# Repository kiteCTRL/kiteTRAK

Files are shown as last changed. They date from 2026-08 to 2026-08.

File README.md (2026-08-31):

# kiteTRAK for PhobGCC

  

## How it Works
A QtPy RP2040 microcontroller is added to the controller to read the PhobGCC state and drive the 128x64 OLED display. The PhobGCC and QtPy RP2040 utilize DMA-based SPI communication for extremely fast comm speeds without interrupting the PhobGCC and maintaining reliable controller functionality. The QtPy RP2040 and OLED display are powered via the 5V line, replacing the rumble motor. The current draw is measured to be 30-40mA, which is about the same current draw as the rumble motor during steady-state use.

Hardware, firmware, and rumble motor bracket 3D model designed by me and top-shell, screen cover, and tall start button 3D models designed by Olympia https://github.com/sean44104 (thank you!).

## Features and Use

### Menu Navigation
PXL_20260826_155146718 (1)  

* Press Z + D-pad Left/Right to navigate the multiple modes with visuals showing which mode you are about to select
* Releasing Z (or while holding, pressing D-pad Up/Down) will exit the menu navigation into the mode you are seeing
* Pressing Z + D-pad Up/Down will navigate the various views within the mode you are in
* Holding Z + Start for 3 seconds on any of the below views will set that to be the default screen after booting
    * There is also a lock icon displayed in the top-right to let you know if your Phob has safe mode enabled (locked icon) or disabled (unlocked icon)

### Button Mode
PXL_20260826_154814305 (1)  

* View main stick and C stick values with visual display
* View analog trigger values and digital button inputs with visual display
* View dashboard of all analog and digital inputs in one simple look  

### IPM Mode
rn_image_picker_lib_temp_c69bd927-668b-4897-ad5c-2858ec075ff4 (1)  

* View your Inputs per Minute (IPM) with a large number in the center of the screen
* View your IPM with a plot showing its change over time
    * If you reach a high-enough IPM, a Balatro-inspired fire animation will be displayed in either view

### Timer Mode
PXL_20260826_160518765 (1)  

* Display the total time since your controller has been plugged in

### Animation Mode
PXL_20260826_160734884 (1)  

* Display a fire animation
* Display a rain animation
* Display a water puddle reactive animation based on digital controller inputs

### Calibration Mode
PXL_20260826_161128514 (1)  

* Display a QR code to access the PhobGCC Calibration guide
* Stick Calibration: A guided process to calibrate either stick, while showing you their exact values with a visual aid
    * If you press D-pad down, this will toggle a help menu for what you are doing at each segment of the calibration process
* A/C-Stick Settings: View your settings for X/Y snapback filtering, waveshaping, smoothing, scaling, and cardinal snapping
    * Holding C stick down during this and all following views will show you help and the button inputs needed to adjust all settings shown
* Trigger Settings: View your settings for L/R trigger modes and L/R offset values
* Button Remaps: View your current button remap settings for A, B, D-pad Up, L, R, X, Y, and Z buttons

---

## Equipment Needed
* Soldering equipment
* Wire strippers
* Flush cutters
* Y1 Tri-Wing screwdriver
* P1 Philips screwdriver
* T6 Torx screwdriver

## Parts Needed

### Controller
* PhobGCC 2.x controller
    * If you are making a new PhobGCC controller for this project, refer to the PhobGCC build guide for details: https://phobgcc.com/For_Makers/Build_Guide_2.0.html
* Custom 3D printed components:
    * Top-shell
    * Screen cover
    * Rumble motor bracket
    * Tall start button
    * Olympia removable gateplate: https://github.com/sean44104/Removable-Gate-GCC

If 3D printing parts with JLCPCB, I recommend the following materials and surface finish:
* Top-shell: JLC Black Resin (more durable) or Imagine Black Resin (better surface finish) with General Sanding
* Screen cover: Imagine Black Resin with General Sanding
* Rumble motor bracket: JLC Black Resin with General Sanding
* Tall start button: Grey Resin (replicates look of OEM start button)
* Olympia removable gateplate: 8001 Resin Transparent with Oil Spraying or 9600R White Resin with General Sanding
    * Note: You will receive a warning for a print thickness <0.8mm with JLC, you can accept this warning

### Electronics
* 1x Adafruit QtPy RP2040 microcontroller
* 1x Adafruit Monochrome 0.96" 128x64 OLED Display
* 1x Adafruit 50mm STEMMA QT cable
* 1x 4pin XA JST header (male and female)
* 1x 2pin XA JST header (male and female)
* 3x 6" XA JST jumper cables
    - All parts above can be found in this DigiKey list: https://www.digikey.com/en/mylists/list/08I1ISAMJL

### Hardware
* 7x M2x0.4mm screw-to-expand press-in inserts (90363A110)
* 3x 6mm M2x0.4mm flat-head Torx screws (90236A104)
* 4x 8mm M2x0.4mm pan-head Torx screws (90304A325)
* Recommended: Multipurpose mineral oil lubricant (1244K14)
    - Part numbers added to find on McMaster-Carr

---

## Installation

### Preparing the Top-shell
  

1. Press in the 7x screw-to-expand threaded inserts in the following positions with the caps facing up:  
    * Note: If threaded inserts do not press fit with just a little force, use the P1 Philips screwdriver to slowly carve away some of the inner plastic materials in the insert posts. Make sure to only remove a small amount of material at a time to avoide loose inserts.

<br>

PXL_20260826_005752434 (1)  

2. After all inserts are installed, use the pan-head Torx screws to expand and tighten down the inserts until flush:  

<br>
  
PXL_20260826_010112606 (1)  

3. Attach the STEMMA QT cable to the right side header of the OLED display and feed it through the gap on the top-shell:  

<br>

PXL_20260826_010610511 (1)  

4. Press the OLED display into place, add screen cover on-top of display, and use the 4x 8mm pan-head Torx screws to mount the screen to the top-shell:  
    * Note: If OLED display does not want to fit into the top-shell, you may need to carve some of the top-shell side material where the headers fit into the gaps. Do NOT force the OLED display as it may break.

<br>

PXL_20260826_010826354 (1)  

5. Press your Olympia removable gateplate into the top-shell and use the 3x flat-head Torx screws to mount the gateplate to the top-shell. Once completed, the top-shell assembly should look like this when complete:
    * Note: Due to print variations, the stick's rubber may contact the gateplate causing a poor feel to stick travel along the notches. To fix, add some filler material inside the stick's post to raise the stick slightly.

<br>

### Installing the QtPy RP2040
  

  

1. Insert and solder the female XA JST headers to the QtPy RP2040 as shown above. Also, trim the soldered pins so they are nearly flush with the PCB.  
    * Note: The headers will be facing opposite directions due to space constraints. Also, the 4-pin XA JST header will sit on the ridge of the reset button, make sure it is not being pressed down when installing.

<br>
  
PXL_20260826_015955598 (1)  

2. Cut the 3x 6" XA JST jumper cables in half to make 6x 3" cables, each with one pin. Strip 4x of the cables to expose the wires on the non-pin ends. Insert and solder the wires into the back-side of the Phob board's GPIO breakout pins labeled GP12-GP15 as shown above:  

<br>
  
rn_image_picker_lib_temp_c13a6599-646f-4fae-9a03-d20db38ac024 (1)  

3. Insert the pins into the XA JST male header with the following wires mounting to the following header holes:  

<br>
  
PXL_20260826_021211120 (1)  

4. With the 2x remaining wires, cut their length down to ~1.5" and strip the non-pin end to expose the wires. Solder one wire to the '+' side of the rumble pin and the other to the square ground pin of the PhobVision pins, located above the rumble pins. Insert the pins into the XA JST male header, routing the ground connection to the left side and the positive connection to the right side of the header in the above orientation:  

<br>

PXL_20260826_022255254 (1)  

5. Fit the 4-pin XA JST header through the opening of the rumble motor bracket and move the 2-pin XA JST header out of the way. Insert the trigger boards into place, and press the rumble motor bracket down as above:  

<br>

PXL_20260826_022522808 (1)  

6. Mount the cable headers into the QtPy RP2040 and move it into the space in the center of the bracket. The installed QtPy RP2040 will sit as shown above:
    * Note: Make sure to route the 4x GPIO wires so they are in front of the 'T' post to avoid interfering with the back-shell when closing. Also, the headers should fit into a small recess that dips down towards the board. 

Now would be a good time to flash the firmware for the Phob board and the QtPy RP2040. Press and hold the reset button on the boards during USB mount to allow flashing the .uf2 files found in [Releases](https://github.com/kiteCTRL/kiteTRAK/releases/latest). Make sure to only have one USB plugged in at a time when flashing. THIS MAY DAMAGE THE PHOB AND QTPY RP2040.

<br>

PXL_20260826_023850832 (1)  

7. Add buttons, making sure to use the tall start button, and button membranes to the top-shell. Move the STEMMA QT cable so that it routes upwards between the small wall piece and the controller cable loop post as shown:  

<br>
  
PXL_20260826_024154263 (1)  

8. Install Phob board into the top-shell, route STEMMA QT cable back towards the QtPy RP2040, and mount it in the left-side header of the QtPy RP2040. Route the controller cable into place.  
    * Note: Make sure the STEMMA QT cable avoids interfering with the trigger potentiometer. You can route the slack of the cable in the loop of the GPIO wires as seen above.

<br>

PXL_20260826_024449589 (1)
  
9. If using a newer GCC shell (like a Smash Ult. controller), you will need to trim this portion of the back-shell to avoid interference with the QtPy RP2040 power cables when closing.

<br>

PXL_20260826_025406819 (2)  

10. If you have the mineral oil lubricant, add 1x drop to each of the screw posts of the top-shell, mount the back-shell, and slowly thread the Tri-wing screws into the controller screw posts. After screws are threaded, open the controller and clean up any of the mineral oil that is left behind. Finally, plug in your controller and confirm the display is working!  

<br>

---
## Project Sources and References
PhobGCC: https://github.com/PhobGCC/PhobGCC-SW  
Olympia removable gateplate: https://github.com/sean44104/Removable-Gate-GCC  

**Disclaimer:** Parts of this project were made with the assistance of AI tools. All generated content has been reviewed and tested by the author, but use it at your own discretion. Graphics, 3D models, and hardware design were made by myself, Olympia, or credited in the files to those who made them; AI was not used for these purposes.

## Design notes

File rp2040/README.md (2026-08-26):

To build PhobGCC with kiteTRAK for the RP2040:

1. Install the compiler toolchain as per the [Pico documentation](https://datasheets.raspberrypi.com/pico/getting-started-with-pico.pdf).
2. Git clone the `pico-sdk` repository from https://github.com/raspberrypi/pico-sdk
3. Check out the master branch.
4. Run `git submodule update --init` (omit `--init` if you're not doing it for the first time)
5. Export the `pico-sdk` directory as an environment variable `export PICO_SDK_PATH=[directory containing]/pico-sdk`
6. Clone the PhobGCC-SW repository.
7. Uncomment the appropriate `#include` line for your board in `../common/phobGCC.h`.
8. `cd` into the `PhobGCC/rp2040` subdirectory inside the `PhobGCC-SW` folder.
9. `mkdir build && cd build`
10. `cmake ..`
11. `make`?

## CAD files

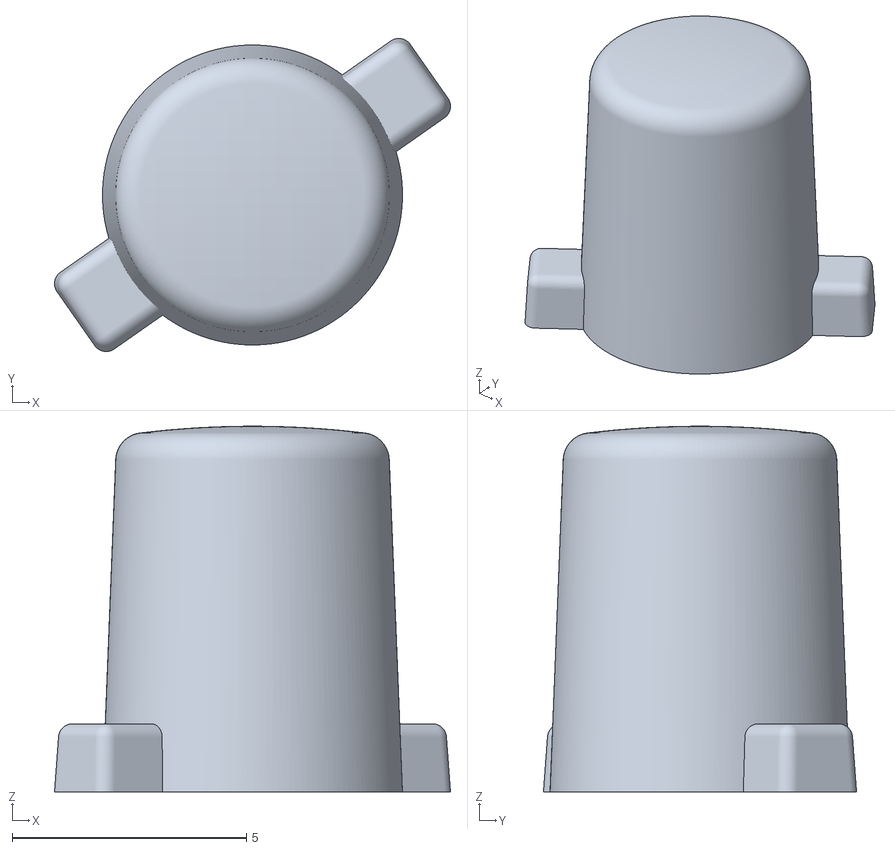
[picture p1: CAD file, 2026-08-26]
3D models/tall-start-button.stl
8.45 x 6.68 x 7.80

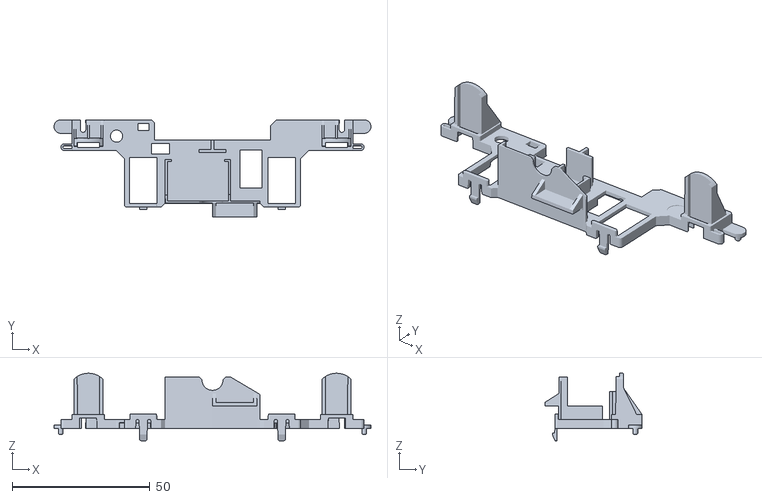
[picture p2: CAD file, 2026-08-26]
3D models/rumble-bracket.stl
115.0 x 35.3 x 24.5

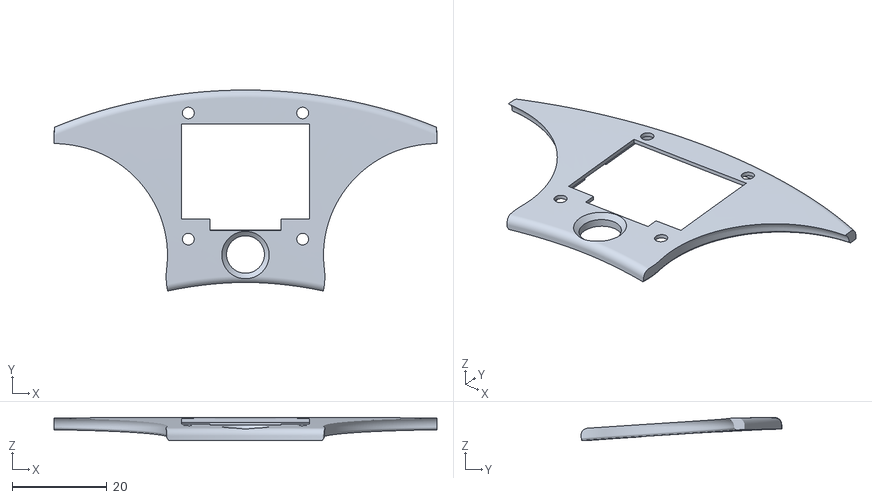
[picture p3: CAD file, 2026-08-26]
3D models/screen-cover.stl
80.9 x 42.4 x 4.87

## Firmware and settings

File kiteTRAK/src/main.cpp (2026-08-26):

#include <stdio.h>
#include <cmath>
#include <EEPROM.h>
#include "hardware/spi.h"
#include "hardware/dma.h"
#include "pico/binary_info.h"
#include "pico/stdlib.h"

#include "kiteTRAK.h"

uint8_t in_buf[BUF_LEN];
uint8_t dma_buf[FRAME_LEN];

// DMA state for non-blocking SPI transfers
static int kt_dma_chan = -1;
static volatile bool kt_dma_busy = false;
static volatile bool kt_dma_data_ready = false;

// DMA IRQ handler forward declaration
static void kt_dma_irq_handler(void);

// DMA IRQ handler: clears DMA interrupt, copies data to input buffer, and marks data ready
static void kt_dma_irq_handler(void) {
  if (kt_dma_chan >= 0) {
    dma_hw->ints0 = 1u << kt_dma_chan; // clear IRQ for our channel
    // Copy received data from DMA buffer to input buffer
    size_t sof_idx = FRAME_LEN;
    for (size_t i = 0; i < FRAME_LEN; ++i) {
      if (dma_buf[i] == SOF_MARKER) {
        sof_idx = i;
        break;
      }
    }

    if (sof_idx < FRAME_LEN &&
        dma_buf[(sof_idx + FRAME_LEN - 1) % FRAME_LEN] == EOF_MARKER) {
      for (size_t i = 0; i < BUF_LEN; ++i) {
        in_buf[i] = dma_buf[(sof_idx + 1 + i) % FRAME_LEN];
      }
    }
    kt_dma_data_ready = true;
  }
  kt_dma_busy = false;
}

Buttons btn;
Buttons oldButton;
PhobConfig phob_config; // PhobGCC configuration data
uint8_t btn_arr1[8];
uint8_t btn_arr2[8];

bool down_pressed = false;
bool button_pressed = false;
int disp_mode = MODE_INPUT; // Default display mode
bool disp_menu = false;

// Default views
int input_view_index = 0;
int ipm_view_index = 0;
int anim_view_index = 0;
int cal_view_index = 0;

// Calibration help menu
bool cal_help_menu = false;
unsigned long last_flash_ms = 0;

struct DefaultScreenSettings {
  uint32_t magic;
  int disp_mode;
  int input_view_index;
  int ipm_view_index;
  int anim_view_index;
  int cal_view_index;
};

const uint32_t DEFAULT_SCREEN_MAGIC = 0x4B54524B;
const unsigned long DEFAULT_SCREEN_HOLD_MS = 3000;
unsigned long default_screen_hold_start = 0;
bool default_screen_hold_active = false;
bool default_screen_saved = false;
unsigned long default_screen_show_until = 0;

// Idle display timeout (2 minutes = 120000 ms)
const unsigned long DISPLAY_TIMEOUT_MS = 120000;
unsigned long last_input_ms = 0;
bool display_is_off = false;

// Safe-mode overlay handling
unsigned long sm_show_until = 0; // timestamp (ms) until which to show overlay
bool sm_state_to_show = false;    // which graphic to show when overlay active
bool sm_initialized = false;     // avoid triggering overlay on first sample
bool prev_safe_mode = false;     // last seen safe_mode state

int input_count = 0;
// Rolling IPM (inputs per minute) buffer settings (0.25s buckets)
const int WINDOW_SECONDS = 6; // total rolling window in seconds
const int BUCKET_MS = 250; // each bucket duration in milliseconds (0.25s)
const int ROLLING_BUCKETS = (WINDOW_SECONDS * 1000) / BUCKET_MS; // 24 buckets for 6s (0.25s buckets)
int bucket_counts[ROLLING_BUCKETS] = {0}; // raw event counts per bucket
int ipm_buffer[ROLLING_BUCKETS] = {0}; // rolling sum (total IPM) snapshot at each bucket boundary for plotting
int ipm_index = 0; // circular buffer index
int events_this_bucket = 0; // events counted in the current 0.25s bucket
unsigned long last_bucket_ms = 0; // last bucket timestamp in ms
int rolling_sum = 0; // sum of counts in buffer
int inputs_per_minute = 0; // computed IPM (scaled from WINDOW_SECONDS)
int max_inputs_per_minute = 0; // track peak IPM
const int IPM_SCALE = 60 / WINDOW_SECONDS; // scale factor to convert window to per-minute (60/6 = 10)
const int MAX_IPM = 1000; // graph vertical axis max in inputs-per-minute
const int IPM_FLAME = 700; // IPM level to trigger flame animation

// Splash animation state
const int MAX_SPLASHES = 30;
struct Splash {
  int x, y;
  unsigned long start_time;
  bool active;
};
Splash splashes[MAX_SPLASHES];

// Core 0 SPI Setup and Loop
//===============================================================//

void setup() {
  spi_init(spi0, 1000*1000); //1MHz Baudrate
  spi_set_slave(spi0, true);

  gpio_set_function(4, GPIO_FUNC_SPI); // MISO (Rx)
  gpio_set_function(6, GPIO_FUNC_SPI); // SCK
  gpio_set_function(3, GPIO_FUNC_SPI); // MOSI (Tx)
  gpio_set_function(5, GPIO_FUNC_SPI); // CS

  // Initialize DMA channel for SPI RX (only once)
  if (kt_dma_chan < 0) {
    kt_dma_chan = dma_claim_unused_channel(true);
    dma_channel_config c = dma_channel_get_default_config(kt_dma_chan);
    channel_config_set_transfer_data_size(&c, DMA_SIZE_8);
    channel_config_set_read_increment(&c, false);  // SPI DR is fixed address
    channel_config_set_write_increment(&c, true);  // Write incrementally to buffer
    channel_config_set_dreq(&c, DREQ_SPI0_RX);    // Use SPI0 RX DMA request
    
    dma_channel_set_config(kt_dma_chan, &c, false);
    dma_channel_set_irq0_enabled(kt_dma_chan, true);
    irq_set_exclusive_handler(DMA_IRQ_0, kt_dma_irq_handler);
    irq_set_enabled(DMA_IRQ_0, true);
  }

  for(size_t i = 0; i < BUF_LEN; ++i) {
    in_buf[i] = 0;
  }
  for(size_t i = 0; i < FRAME_LEN; ++i) {
    dma_buf[i] = 0;
  }
}

void loop() {
  if (spi_is_readable(spi0)) {
    // If DMA available and not busy, kick off a non-blocking DMA transfer
    if (kt_dma_chan >= 0 && !kt_dma_busy) {
      kt_dma_busy = true;
      kt_dma_data_ready = false;
      
      // Configure and start DMA transfer: read from SPI0 DR, write to dma_buf
      dma_channel_config c = dma_channel_get_default_config(kt_dma_chan);
      channel_config_set_transfer_data_size(&c, DMA_SIZE_8);
      channel_config_set_read_increment(&c, false);   // SPI DR is fixed address
      channel_config_set_write_increment(&c, true);   // Write incrementally to buffer
      channel_config_set_dreq(&c, DREQ_SPI0_RX);      // Use SPI0 RX DMA request
      
      dma_channel_configure(kt_dma_chan, &c,
                            dma_buf,                // destination: DMA buffer
                            &spi_get_hw(spi0)->dr,  // source: SPI data register
                            FRAME_LEN,             // transfer count
                            true);                  // start immediately
    }
  }
}

// Core 1 Display Setup and Loop
//===============================================================//

void setup1() {
  busy_wait_ms(150);
  display.begin(SSD1306_SWITCHCAPVCC, SCREEN_ADDRESS);
  display.clearDisplay();

  EEPROM.begin(sizeof(DefaultScreenSettings));
  DefaultScreenSettings default_screen;
  EEPROM.get(0, default_screen);
  if (default_screen.magic == DEFAULT_SCREEN_MAGIC &&
      default_screen.disp_mode >= 0 && default_screen.disp_mode < NUM_MODES &&
      default_screen.input_view_index >= 0 && default_screen.input_view_index < 3 &&
      default_screen.ipm_view_index >= 0 && default_screen.ipm_view_index < 2 &&
      default_screen.anim_view_index >= 0 && default_screen.anim_view_index < 3 &&
      default_screen.cal_view_index >= 0 && default_screen.cal_view_index < 7) {
    disp_mode = default_screen.disp_mode;
    input_view_index = default_screen.input_view_index;
    ipm_view_index = default_screen.ipm_view_index;
    anim_view_index = default_screen.anim_view_index;
    cal_view_index = default_screen.cal_view_index;
  }

  // Initialize splash array
  for (int i = 0; i < MAX_SPLASHES; i++) {
    splashes[i].active = false;
  }

  // Initialize last input time
  last_input_ms = to_ms_since_boot(get_absolute_time());

  boot_animation(); // comment out to skip boot animation 
}

void loop1() {
  // Assign button states to btn
  assign_buttons(btn, in_buf);

  // Parse PhobGCC configuration data
  parse_phob_config(phob_config, in_buf);

  // Check for any input activity to track idle timeout
  unsigned long now_ms = to_ms_since_boot(get_absolute_time());
  
  // Check for controller being idle
  if (btn.A == 1 || btn.B == 1 || btn.X == 1 || 
      btn.Y == 1 || btn.Z == 1 || btn.S == 1 ||
      btn.L == 1 || btn.R == 1 || btn.Dl == 1 ||
      btn.Dr == 1 || btn.Du == 1 || btn.Dd == 1) {
    last_input_ms = now_ms;
    display_is_off = false;
  }
  
  // Check if display should be turned off due to inactivity
  if (!display_is_off && (now_ms - last_input_ms) > DISPLAY_TIMEOUT_MS) {
    display_is_off = true;
  }
  
  // If display is off, show black screen and return early
  if (display_is_off) {
    display.ssd1306_command(SSD1306_DISPLAYOFF);
    oldButton = btn; // Still update oldButton to detect when input resumes
    return;
  } else {
    display.ssd1306_command(SSD1306_DISPLAYON);
  }

  // Save the current screen as the boot default after holding Z + Start for 3 seconds.
  if (btn.Z && btn.S) {
    if (!default_screen_hold_active) {
      default_screen_hold_active = true;
      default_screen_hold_start = now_ms;
    } else if (!default_screen_saved &&
               now_ms - default_screen_hold_start >= DEFAULT_SCREEN_HOLD_MS) {
      DefaultScreenSettings default_screen = {
        DEFAULT_SCREEN_MAGIC,
        disp_mode,
        input_view_index,
        ipm_view_index,
        anim_view_index,
        cal_view_index
      };
      EEPROM.put(0, default_screen);
      EEPROM.commit();
      default_screen_saved = true;
      default_screen_show_until = now_ms + 2000;
    }
  } else {
    default_screen_hold_active = false;
    default_screen_saved = false;
  }

  // Detect safe_mode changes and trigger 2s overlay when changed
  if (!sm_initialized) {
    prev_safe_mode = phob_config.safe_mode;
    sm_initialized = true;
  } else if (phob_config.safe_mode != prev_safe_mode) {
    // record which graphic to show and show for 2 seconds
    sm_state_to_show = phob_config.safe_mode; // true => enabled, false => disabled
    sm_show_until = now_ms + 2000;
    prev_safe_mode = phob_config.safe_mode;
  }

  // Check if safe-mode overlay should be shown
  bool show_sm_overlay = (now_ms < sm_show_until && !disp_menu);
  bool show_default_screen_overlay = (now_ms < default_screen_show_until && !disp_menu);

  // If overlay is active, skip normal rendering and show overlay
  if (show_sm_overlay || show_default_screen_overlay) {
    display.clearDisplay();
    if (show_sm_overlay && sm_state_to_show) {
      draw_sm_enabled();
    } else if (show_sm_overlay) {
      draw_sm_disabled();
    } else {
      draw_boot_screen();
    }
    display.display();
    return; // Skip normal display mode rendering
  }

  // Display Modes
  //=============================================================//

  // Display Input (sticks / buttons) and allow cycling with D-pad down
  if (disp_mode == MODE_INPUT && !disp_menu) {
    display.clearDisplay();

    if (input_view_index == 0) {
      // Sticks view
      display_stick(btn, "a");
      display.setCursor(0, 46);
      display.printf("Ax:% 7.4f", btn.Ax_melee);
      display.setCursor(0, 55);
      display.printf("Ay:% 7.4f", btn.Ay_melee);

      display_stick(btn, "c");
      display.setCursor(68, 0);
      display.printf("Cx:% 7.4f", btn.Cx_melee);
      display.setCursor(68, 9);
      display.printf("Cy:% 7.4f", btn.Cy_melee);
    } else if (input_view_index == 1) {
      // Buttons view
      draw_dpad(2, 0);
      display.drawCircle(93, 28, 10, 1);                  // a
      display.drawCircle(81, 42, 5, 1);                   // b
      display.drawBitmap(98, 10, xbutton_bmp, 15, 13, 1); // x
      display.drawBitmap(74, 10, ybutton_bmp, 15, 13, 1); // y
      display.drawRoundRect(93, 1, 20, 5, 2, 1);          // z
      display.drawCircle(59, 51, 3, 1);                   // start
      // L trigger: outline box (filled upward based on btn.La value)
      display.drawRect(2, 1, 7, 54, 1);
      int la_fill_height = (btn.La * 54) / 255; // scale 0-255 to 0-54 pixels
      if (la_fill_height > 0) {
        display.fillRect(2, 55 - la_fill_height, 7, la_fill_height, 1); // fill upward from bottom
      }

      // R trigger: outline box (filled upward based on btn.Ra value)
      display.drawRect(119, 1, 7, 54, 1);
      int ra_fill_height = (btn.Ra * 54) / 255; // scale 0-255 to 0-54 pixels
      if (ra_fill_height > 0) {
        display.fillRect(119, 55 - ra_fill_height, 7, ra_fill_height, 1); // fill upward from bottom
      }

      // Trigger value readouts beneath
      display.setTextSize(1);
      display.setFont();
      display.setCursor(0, 57);
      display.printf("%03d", btn.La);
      display.setCursor(111, 57);
      display.printf("%03d", btn.Ra);

      if (btn.A) {
        display.fillCircle(93, 28, 10, 1);
      }
      if (btn.B) {
        display.fillCircle(81, 42, 5, 1);
      }
      if (btn.X) {
        display.drawBitmap(98, 10, xbutton_pressed_bmp, 15, 13, 1);
      }
      if (btn.Y) {
        display.drawBitmap(74, 10, ybutton_pressed_bmp, 15, 13, 1);
      }
      if (btn.Z) {
        display.fillRoundRect(93, 1, 20, 5, 2, 1);
      }
      if (btn.S) {
        display.fillCircle(59, 51, 3, 1);
      }
      if (btn.Dl) {
        display.fillRect(22, 27, 9, 5, 1);
      }
      if (btn.Dr) {
        display.fillRect(36, 27, 9, 5, 1);
      }
      if (btn.Du) {
        display.fillRect(31, 18, 5, 9, 1);
      }
      if (btn.Dd) {
        display.fillRect(31, 32, 5, 9, 1);
      }
      if (btn.L) {
        display.fillRect(2, 1, 7, 54, 1);
      }
      if (btn.R) {
        display.fillRect(119, 1, 7, 54, 1);
      }

    } else if (input_view_index == 2) {
      // Button/Sticks dashboard view
      display_buttons_dash(btn, in_buf);
    } 
    
    display.display();

    // Cycle between input sub-views with D-pad down/up (debounced)
    if (btn.Dd && btn.Z && !down_pressed) {
      input_view_index = (input_view_index + 1) % 3; // 0=sticks,1=buttons,2=dashboard
      down_pressed = true;
    } else if (btn.Du && btn.Z && !down_pressed) {
      input_view_index = (input_view_index - 1 + 3) % 3; // cycle backwards
      down_pressed = true;
    } else if (!btn.Dd && !btn.Du) {
      down_pressed = false;
    }
  }

  // Display Inputs Per Minute (IPM) Visuals
  if (disp_mode == MODE_IPM && !disp_menu) {

    if (btn.A && !oldButton.A) events_this_bucket++;
    if (btn.B && !oldButton.B) events_this_bucket++;
    if (btn.X && !oldButton.X) events_this_bucket++;
    if (btn.Y && !oldButton.Y) events_this_bucket++;
    if (btn.L && !oldButton.L) events_this_bucket++;
    if (btn.R && !oldButton.R) events_this_bucket++;
    if (btn.Z && !oldButton.Z) events_this_bucket++;

    if ((btn.Ax-ORG >= 23 && oldButton.Ax-ORG < 23) || (abs(btn.Ax-ORG) < 23 && abs(oldButton.Ax-ORG) >= 23) || (btn.Ax-ORG <= -23 && oldButton.Ax-ORG > -23)) events_this_bucket++;
    if ((btn.Ay-ORG >= 23 && oldButton.Ay-ORG < 23) || (abs(btn.Ay-ORG) < 23 && abs(oldButton.Ay-ORG) >= 23) || (btn.Ay-ORG <= -23 && oldButton.Ay-ORG > -23)) events_this_bucket++;
    if ((btn.Cx-ORG >= 23 && oldButton.Cx-ORG < 23) || (abs(btn.Cx-ORG) < 23 && abs(oldButton.Cx-ORG) >= 23) || (btn.Cx-ORG <= -23 && oldButton.Cx-ORG > -23)) events_this_bucket++;
    if ((btn.Cy-ORG >= 23 && oldButton.Cy-ORG < 23) || (abs(btn.Cy-ORG) < 23 && abs(oldButton.Cy-ORG) >= 23) || (btn.Cy-ORG <= -23 && oldButton.Cy-ORG > -23)) events_this_bucket++;

    // update oldButton snapshot
    oldButton = btn;

    // Update rolling buffer at bucket boundaries (every BUCKET_MS)
    unsigned long now_ms = to_ms_since_boot(get_absolute_time());
    unsigned long now_bucket = now_ms / BUCKET_MS;
    unsigned long last_bucket = last_bucket_ms / BUCKET_MS;
    if (now_bucket != last_bucket) {
      // Subtract outgoing bucket count from rolling sum
      rolling_sum -= bucket_counts[ipm_index];
      // Store new bucket event count
      bucket_counts[ipm_index] = events_this_bucket;
      // Add incoming bucket count to rolling sum
      rolling_sum += bucket_counts[ipm_index];
      // Store rolling sum (in IPM units) for plotting
      ipm_buffer[ipm_index] = rolling_sum;
      ipm_index = (ipm_index + 1) % ROLLING_BUCKETS;

      // compute IPM (which is already the rolling_sum)
      inputs_per_minute = rolling_sum * IPM_SCALE;
      
      // update max IPM if current exceeds it
      if (inputs_per_minute > max_inputs_per_minute) {
        max_inputs_per_minute = inputs_per_minute;
      }

      // reset counter for new bucket and update timestamp
      events_this_bucket = 0;
      last_bucket_ms = now_ms;
    }
      // Toggle minimal view with D-pad down/up (debounced)
      if (btn.Dd && btn.Z && !down_pressed) {
        ipm_view_index = (ipm_view_index + 1) % 2; // 0=full,1=minimal
        down_pressed = true;
      } else if (btn.Du && btn.Z && !down_pressed) {
        ipm_view_index = (ipm_view_index - 1 + 2) % 2; // cycle backwards
        down_pressed = true;
      } else if (!btn.Dd && !btn.Du) {
        down_pressed = false;
      }

      if (ipm_view_index == 0) {
        // Minimal: show only IPM label and numeric value
        display.clearDisplay();
        display.setTextSize(1);
        display.setTextColor(SSD1306_WHITE);
        display.setFont();
        display.setCursor(73, 4);
        display.print("Max:");
        display.setCursor(102, 4);
        display.print(max_inputs_per_minute);

        display.setFont(&FreeSansBoldOblique12pt7b);
        
        // Measure text width to center horizontally
        int16_t x1, y1;
        uint16_t w, h;
        char ipm_str[16];
        snprintf(ipm_str, sizeof(ipm_str), "%d", inputs_per_minute);
        display.getTextBounds(ipm_str, 0, 0, &x1, &y1, &w, &h);
        
        // Center x and position y
        int text_x = (SCREEN_WIDTH - w) / 2;
        display.setCursor(text_x, 40);
        display.print(ipm_str);

        if (inputs_per_minute > IPM_FLAME) {
          static int flame_frame = 0;
          display.drawBitmap(0, 12, epd_bitmap_allArray_flame[flame_frame], 128, 64, SSD1306_WHITE);
          flame_frame = (flame_frame + 1) % 157;
        }

        display.display();
      } else {
        display.clearDisplay();

        // Header: IPM value (full view)
        display.setTextSize(1);
        display.setTextColor(SSD1306_WHITE);
        display.setFont();
        display.setCursor(2, 4);
        display.print("IPM:");
        display.setCursor(32, 4);
        display.print(inputs_per_minute);
        display.setCursor(73, 4);
        display.print("Max:");
        display.setCursor(102, 4);
        display.print(max_inputs_per_minute);

        if (inputs_per_minute > IPM_FLAME) {
          static int flame_frame = 0;
          display.drawBitmap(0, 12, epd_bitmap_allArray_flame[flame_frame], 128, 64, SSD1306_WHITE);
          flame_frame = (flame_frame + 1) % 157;
        }

        // Small moving bar graph of per-bucket counts
        const int graph_x = 0;
        const int graph_y = 12;
        const int graph_w = 128;
        const int graph_h = 52;
        const int buckets = ROLLING_BUCKETS; // should be 24
        int bar_w = graph_w / buckets; // integer width per bar

        // Fixed scaling: graph axis is directly in IPM (0 to MAX_IPM)
        float scale = (float)graph_h / (float)MAX_IPM; // pixels per IPM

        // Draw border for graph area at screen edges
        display.drawRect(0, 12, 128, 52, SSD1306_WHITE);

        // Draw connected line plot: oldest at left (ipm_index is next write slot)
        int prev_x = 0;
        int prev_y = 0;
        bool has_prev = false;
        for (int k = 0; k < buckets; ++k) {
          int buf_idx = (ipm_index + k) % buckets;
          int v = ipm_buffer[buf_idx]; // v is in raw event counts
          // Convert to IPM for scaling
          int v_ipm = v * IPM_SCALE;
          // center x of the bucket
          int x = graph_x + k * bar_w + (bar_w / 2);
          // y coordinate: invert so larger values are higher on screen
          int y = graph_y + graph_h - (int)(v_ipm * scale + 0.5f);

          // clamp y within graph bounds
          if (y < graph_y) y = graph_y;
          if (y > graph_y + graph_h) y = graph_y + graph_h;

          if (has_prev) {
            display.drawLine(prev_x, prev_y, x, y, SSD1306_WHITE);
          }
          // draw a pixel/point at the sample
          display.drawPixel(x, y, SSD1306_WHITE);
          prev_x = x;
          prev_y = y;
          has_prev = true;
        }

        display.display();
      }
  }

  // Display Animations (rain / fire) and allow cycling with D-pad down
  if (disp_mode == MODE_ANIMATIONS && !disp_menu) {
    display.clearDisplay();

    static int rain_frame = 0;
    static int flame_frame = 0;
    static unsigned long last_frame_ms = 0;
    unsigned long now_ms = to_ms_since_boot(get_absolute_time());

    // Update frame every ~33ms for ~30 fps
    if (now_ms - last_frame_ms >= 33) {
      if (anim_view_index == 0) {
        rain_frame = (rain_frame + 1) % 47;
      } else {
        flame_frame = (flame_frame + 1) % 157;
      }
      last_frame_ms = now_ms;
    }
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

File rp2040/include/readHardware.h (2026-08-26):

#ifndef READHARDWARE_H
#define READHARDWARE_H

//include this after the pins are defined in the RP2040 board-specific headers

#include <cmath>
#include <stdint.h>

#include "pico/stdlib.h"
#include "hardware/gpio.h"
#include "hardware/adc.h"
#include "hardware/spi.h"
#include "hardware/timer.h"

#include "structsAndEnums.h"
#include "storage/pages/storage.h"
#include "extras.h"

void setPinModes() {
	gpio_init(_pinA);
	gpio_pull_up(_pinA);
	gpio_set_dir(_pinA, GPIO_IN);
	gpio_init(_pinB);
	gpio_pull_up(_pinB);
	gpio_set_dir(_pinB, GPIO_IN);
	gpio_init(_pinDr);
	gpio_pull_up(_pinDr);
	gpio_set_dir(_pinDr, GPIO_IN);
	gpio_init(_pinDu);
	gpio_pull_up(_pinDu);
	gpio_set_dir(_pinDu, GPIO_IN);
	gpio_init(_pinDl);
	gpio_pull_up(_pinDl);
	gpio_set_dir(_pinDl, GPIO_IN);
	gpio_init(_pinDd);
	gpio_pull_up(_pinDd);
	gpio_set_dir(_pinDd, GPIO_IN);
	gpio_init(_pinL);
	gpio_pull_up(_pinL);
	gpio_set_dir(_pinL, GPIO_IN);
	gpio_init(_pinR);
	gpio_pull_up(_pinR);
	gpio_set_dir(_pinR, GPIO_IN);
	gpio_init(_pinX);
	gpio_pull_up(_pinX);
	gpio_set_dir(_pinX, GPIO_IN);
	gpio_init(_pinY);
	gpio_pull_up(_pinY);
	gpio_set_dir(_pinY, GPIO_IN);
	gpio_init(_pinZ);
	gpio_pull_up(_pinZ);
	gpio_set_dir(_pinZ, GPIO_IN);
	gpio_init(_pinS);
	gpio_pull_up(_pinS);
	gpio_set_dir(_pinS, GPIO_IN);

	/* the comms library sets this
	gpio_init(_pinTx);
	gpio_set_dir(_pinTx, GPIO_IN);
	gpio_pull_up(_pinTx);
	*/

#ifndef EXTRAS_KT
	//Rumble
    gpio_init(_pinRumble);
    gpio_init(_pinBrake);
    gpio_set_dir(_pinRumble, GPIO_OUT);
    gpio_set_dir(_pinBrake, GPIO_OUT);
    gpio_set_function(_pinRumble, GPIO_FUNC_PWM);
    gpio_set_function(_pinBrake,  GPIO_FUNC_PWM);
    const uint rumbleSlice_num = pwm_gpio_to_slice_num(_pinRumble);
    const uint brakeSlice_num  = pwm_gpio_to_slice_num(_pinBrake);
    pwm_set_wrap(rumbleSlice_num, 255);
    pwm_set_wrap(brakeSlice_num,  255);
    pwm_set_chan_level(rumbleSlice_num, PWM_CHAN_B, 0);//B for odd pins
    pwm_set_chan_level(brakeSlice_num,  PWM_CHAN_B, 255);//B for odd pins
    pwm_set_enabled(rumbleSlice_num, true);
    pwm_set_enabled(brakeSlice_num,  true);
#endif

#ifdef EXTRAS_KT
	kt::rumble_pin_setup();
#endif

	//initialize SPI at 1 MHz
	//initialize SPI at 3 MHz just to test
	spi_init(spi0, 3000*1000);
	gpio_set_function(_pinSPIclk, GPIO_FUNC_SPI);
	gpio_set_function(_pinSPItx, GPIO_FUNC_SPI);
	gpio_set_function(_pinSPIrx, GPIO_FUNC_SPI);
	gpio_init(_pinAcs);
	gpio_set_dir(_pinAcs, GPIO_OUT);
	gpio_put(_pinAcs, 1);//active low
	gpio_init(_pinCcs);
	gpio_set_dir(_pinCcs, GPIO_OUT);
	gpio_put(_pinCcs, 1);//active low

	//initialize ADC for triggers
	adc_init();
	adc_gpio_init(_pinLa);
	adc_gpio_init(_pinRa);

	//initialize DAC outputs
	gpio_init(_pinDac0);
	gpio_init(_pinDac1);
	gpio_init(_pinDac2);
	gpio_init(_pinDac3);
	gpio_set_dir(_pinDac0, GPIO_OUT);
	gpio_set_dir(_pinDac1, GPIO_OUT);
	gpio_set_dir(_pinDac2, GPIO_OUT);
	gpio_set_dir(_pinDac3, GPIO_OUT);

#ifndef EXTRAS_KT
	//initialize spare outputs
	gpio_init(_pinSpare0);
	gpio_set_dir(_pinSpare0, GPIO_OUT);
	gpio_init(_pinSpare1);
	gpio_set_dir(_pinSpare1, GPIO_OUT);
	gpio_init(_pinSpare2);
	gpio_set_dir(_pinSpare2, GPIO_OUT);
	gpio_init(_pinLED);
	gpio_set_dir(_pinLED, GPIO_OUT);
#endif

#ifdef EXTRAS_KT
	kt::SPI_setup();
#endif
}

void readButtons(const Pins &, Buttons &hardware) {
	hardware.A  = !gpio_get(_pinA);
	hardware.B  = !gpio_get(_pinB);
	hardware.X  = !gpio_get(_pinX);
	hardware.Y  = !gpio_get(_pinY);
	hardware.L  = !gpio_get(_pinL);
	hardware.R  = !gpio_get(_pinR);
	hardware.Z  = !gpio_get(_pinZ);
	hardware.S  = !gpio_get(_pinS);
	hardware.Dr = !gpio_get(_pinDr);
	hardware.Du = !gpio_get(_pinDu);
	hardware.Dl = !gpio_get(_pinDl);
	hardware.Dd = !gpio_get(_pinDd);
}

void readADCScale(float &, float ) {
	//do nothing
}

//implement a 3 unit deadzone
int readLa(const Pins &, const int initial, const float scale) {
	adc_select_input(_pinLadc);
	float temp = adc_read() / 16.0;
	if(temp < 3) {
		temp = 0.0f;
	}
	return fmin(255, fmax(0, temp - initial) * scale);
}
int readRa(const Pins &, const int initial, const float scale) {
	adc_select_input(_pinRadc);
	float temp = adc_read() / 16.0;
	if(temp < 3) {
		temp = 0.0f;
	}
	return fmin(255, fmax(0, temp - initial) * scale);
}
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

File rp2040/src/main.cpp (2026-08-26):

#include "pico/stdlib.h"
#include "pico/bootrom.h"
#include "pico/multicore.h"
#include "hardware/timer.h"
#include "hardware/pwm.h"

#include "phobGCC.h"
#include "comms/joybus.hpp"
#include "cvideo.h"
#include "cvideo_variables.h"
#include "hardware/clocks.h"

volatile bool _videoOut = false;
//Variables used by PhobVision to communicate with the event loop core
volatile bool _sync = false;
volatile uint8_t _pleaseCommit = 0;//255 = redraw please
int _currentCalStep = -1;//-1 means not calibrating
int _currentRemapStep = -1;//-1 means not remapping
bool _currentlyRaw = false;
DataCapture _dataCapture;

//This gets called by the comms library
GCReport __no_inline_not_in_flash_func(buttonsToGCReport)() {
	GCReport report = {{
		.a       = _btn.A,
		.b       = _btn.B,
		.x       = _btn.X,
		.y       = _btn.Y,
		.start   = _btn.S,
		.pad0    = 0,
		.dLeft   = _btn.Dl,
		.dRight  = _btn.Dr,
		.dDown   = _btn.Dd,
		.dUp     = _btn.Du,
		.z       = _btn.Z,
		.r       = _btn.R,
		.l       = _btn.L,
		.pad1    = 1,
		.xStick  = _btn.Ax,
		.yStick  = _btn.Ay,
		.cxStick = _btn.Cx,
		.cyStick = _btn.Cy,
		.analogL = _btn.La,
		.analogR = _btn.Ra
	}};
	return report;
}

void second_core() {

#ifndef EXTRAS_KT
	gpio_set_function(_pinLED, GPIO_FUNC_PWM);
	uint slice_num = pwm_gpio_to_slice_num(_pinLED);
	pwm_set_wrap(slice_num, 255);
	pwm_set_chan_level(slice_num, PWM_CHAN_B, 25);
	pwm_set_enabled(slice_num, true);
#endif

	extrasInit();

	while(true) { //main event loop
		//Set up persistent storage for calibration
		static float tempCalPointsX[_noOfCalibrationPoints];
		static float tempCalPointsY[_noOfCalibrationPoints];
		static WhichStick whichStick = ASTICK;
		static NotchStatus notchStatus[_noOfNotches];
		static float notchAngles[_noOfNotches];
		static float measuredNotchAngles[_noOfNotches];
		static bool advanceCal = false;
		static bool undoCal = false;

#ifdef EXTRAS_KT
		kt::SPI_transfer(_btn.arr, _currentCalStep, _controls.safeMode, _controls.extras[kt::extrasKtConfigSlot].config, _btn.B, _controls, whichStick);
#endif

		//when requested by the other core, commit the settings
		if(_pleaseCommit != 0) {
			if(_pleaseCommit == 1) {
				_pleaseCommit = 0;
				recomputeGains(_controls, _gains, _normGains);
				commitSettings();
			} else if(_pleaseCommit == 2) {
				_pleaseCommit = 0;
				resetDefaults(SOFT, _controls, _gains, _normGains, _aStickParams, _cStickParams);
			} else if(_pleaseCommit == 3) {
				_pleaseCommit = 0;
				resetDefaults(HARD, _controls, _gains, _normGains, _aStickParams, _cStickParams);
			} else if(_pleaseCommit == 4) {
				//Advance cal, A-stick
				_pleaseCommit = 255;
				whichStick = ASTICK;
				if(_currentCalStep == -1) {
					_currentCalStep++;
				}
				calibrationAdvance(_controls, _currentCalStep, whichStick, tempCalPointsX, tempCalPointsY, undoCal, notchAngles, notchStatus, measuredNotchAngles, _aStickParams, _cStickParams);
			} else if(_pleaseCommit == 5) {
				//Advance cal, C-stick
				_pleaseCommit = 255;
				whichStick = CSTICK;
				if(_currentCalStep == -1) {
					_currentCalStep++;
				}
				calibrationAdvance(_controls, _currentCalStep, whichStick, tempCalPointsX, tempCalPointsY, undoCal, notchAngles, notchStatus, measuredNotchAngles, _aStickParams, _cStickParams);
			} else if(_pleaseCommit == 6) {
				//undo cal
				_pleaseCommit = 255;
				calibrationUndo(_currentCalStep, whichStick, notchStatus);
			} else if(_pleaseCommit == 7) {
				//skip cal (might not actually get used?) (it's available but not shown)
				_pleaseCommit = 255;
				calibrationSkipMeasurement(_currentCalStep, whichStick, tempCalPointsX, tempCalPointsY, notchStatus, notchAngles, measuredNotchAngles, _aStickParams, _cStickParams, _controls);
			} else if(_pleaseCommit == 8) {
				_pleaseCommit = 0;
				_rumblePower = calcRumblePower(_controls.rumble);
				//rumble for 0.3 seconds
				pwm_set_gpio_level(_pinBrake, 0);
				pwm_set_gpio_level(_pinRumble, _rumblePower);
				int startTime = millis();
				int delta = 0;
				while(delta < 300) {
					delta = millis() - startTime;
				}
				pwm_set_gpio_level(_pinRumble, 0);
				pwm_set_gpio_level(_pinBrake, 255);
			} else if(_pleaseCommit == 9) {
				switch(_dataCapture.mode) {
					//make sure that we can write 200 things in a1 (clobbering a2) for longer recording
					//this is used for single-axis recording
					static_assert(&_dataCapture.a1[100] == &_dataCapture.a2[0]);
					static_assert(&_dataCapture.a1Unfilt[100] == &_dataCapture.a2Unfilt[0]);

					case CM_REACTION:
						//this expects that you initialize data capture by setting delay to 0
						_dataCapture.delay++;
						if(
								//_btn.arr[0] & 0b11110000 ||//abxy
								//_btn.arr[1] & 0b11111110 ||//dpad, lrz
								_btn.arr[0] & 0b00001111 ||//abxy
								_btn.arr[1] & 0b01111111 ||//dpad, lrz
								max(max(abs(int(_btn.Ax)-127), abs(int(_btn.Ay)-127)),
									max(abs(int(_btn.Cx)-127), abs(int(_btn.Cy)-127))) >= _dataCapture.stickThresh ||
								max(_btn.La, _btn.Ra) >= _dataCapture.triggerThresh) {
							_dataCapture.done = true;
							_pleaseCommit = 255;//end capture and display
						}
						break;
					case CM_STICK_RISE2:
						//100 points of 2-axis data
						//this begins capturing data immediately in a rolling buffer,
						//and on detecting a rising edge it begins recording
						//this records the starting point only the first time, then it sets begin
						static int x0;
						static int y0;
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
